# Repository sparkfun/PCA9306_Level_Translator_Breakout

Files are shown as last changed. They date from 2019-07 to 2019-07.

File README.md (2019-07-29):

PCA9306 Level Translator Breakout
=================================

PCA9306 Level Translator Breakout (https://www.sparkfun.com/products/15439)

[*PCA9306 Level Translator Breakout(BOB-15439)*](https://www.sparkfun.com/products/15439)

This is a breakout board for the PCA9306 dual bidirectional voltage-level translator. 

Repository Contents
-------------------
* **/Hardware** - Eagle design files for the board (.brd, .sch)

Documentation
--------------
* **[Hookup Guide](https://learn.sparkfun.com/tutorials/pca9306-logic-level-translator-hookup-guide-v2)** - Basic hookup guide for the PCA9306 logic level translator.
* **[Logic Levels](https://learn.sparkfun.com/tutorials/logic-levels)**
* **[SparkFun Fritzing repo](https://github.com/sparkfun/Fritzing_Parts)** - Fritzing diagrams for SparkFun products.

License Information
-------------------
The hardware is released under [Creative Commons Share-alike 3.0](http://creativecommons.org/licenses/by-sa/3.0/).

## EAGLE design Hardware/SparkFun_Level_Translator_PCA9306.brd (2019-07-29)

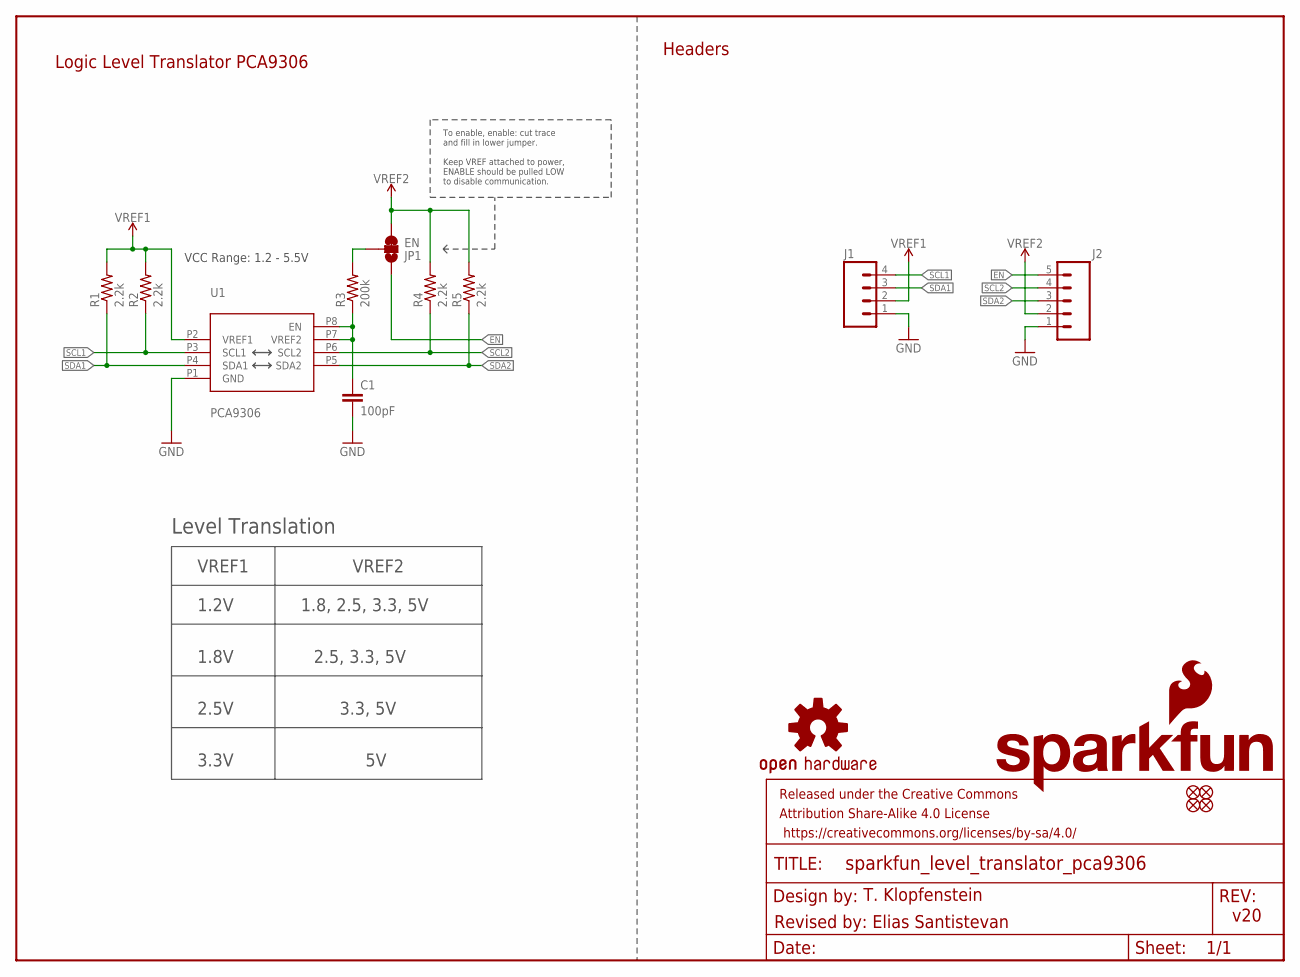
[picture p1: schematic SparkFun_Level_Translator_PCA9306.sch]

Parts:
C1: 100pF; 0603
FD1, FD2, FD3, FD4: FIDUCIALUFIDUCIAL; FIDUCIAL-MICRO
FRAME1: FRAME-LETTER; CREATIVE_COMMONS
J1: CONN_041X04_NO_SILK; 1X04_NO_SILK
J2: CONN_05NO_SILK; 1X05_NO_SILK
JP1: EN; SMT-JUMPER_3_1-NC_TRACE_SILK
LOGO1: OSHW-LOGOMINI; OSHW-LOGO-MINI
LOGO2: SFE_LOGO_NAME.1_INCH; SFE_LOGO_NAME_.1
LOGO3: SFE_LOGO_FLAME.1_INCH; SFE_LOGO_FLAME_.1
R1, R2, R4, R5: 2.2k; 0603
R3: 200k; 0603
U1: PCA9306; VSSOP_8PIN

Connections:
EN: J2.5, JP1.1
GND: C1.2, J1.1, J2.1, U1.P1 (GND)
JUMPER_IN: JP1.2, R3.2
SCL1: J1.4, R2.1, U1.P3 (SCL1)
SCL2: J2.4, R4.1, U1.P6 (SCL2)
SDA1: J1.3, R1.1, U1.P4 (SDA1)
SDA2: J2.3, R5.1, U1.P5 (SDA2)
VREF1: J1.2, R1.2, R2.2, U1.P2 (VREF1)
VREF2: J2.2, JP1.3, R4.2, R5.2
VREF2_IN: C1.1, R3.1, U1.P7 (VREF2), U1.P8 (EN)

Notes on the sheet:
T. Klopfenstein
v20
Logic Level Translator PCA9306
Headers
Revised by: Elias Santistevan
Level Translation
VREF1
VREF2
1.2V
1.8, 2.5, 3.3, 5V
1.8V
2.5, 3.3, 5V
2.5V
3.3, 5V
3.3V
VCC Range: 1.2 - 5.5V
To enable, enable: cut trace and fill in lower jumper.
Keep VREF attached to power, ENABLE should be pulled LOW to disable communication.

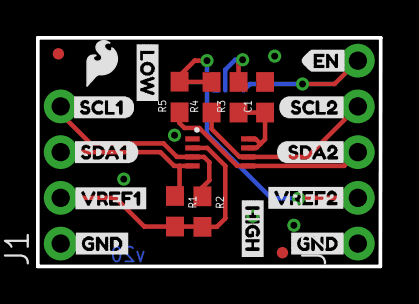
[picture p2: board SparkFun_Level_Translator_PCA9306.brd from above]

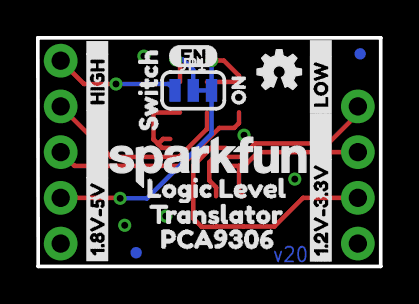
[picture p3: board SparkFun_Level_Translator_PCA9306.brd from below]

Board: 2 copper layers, 19.1 x 12.7 mm, 39 parts (15 on the bottom side), 10 nets.

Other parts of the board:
U$1: SWITCH1
U$2: VREF13
U$3: SCL11
U$4: SDA10
U$5, U$11: GND2
U$6: VREF20
U$7: SCL20
U$8: SDA21
U$9: EN0
U$10: EN1
U$12: LOGIC_LEVEL0
U$13: TRANSLATOR1
U$14: PCA93062
U$15: ON2
U$17, U$19: HIGH0
U$18, U$20: LOW1
U$21: 1#2V#3#3V0
U$22: 1#8V#5V1

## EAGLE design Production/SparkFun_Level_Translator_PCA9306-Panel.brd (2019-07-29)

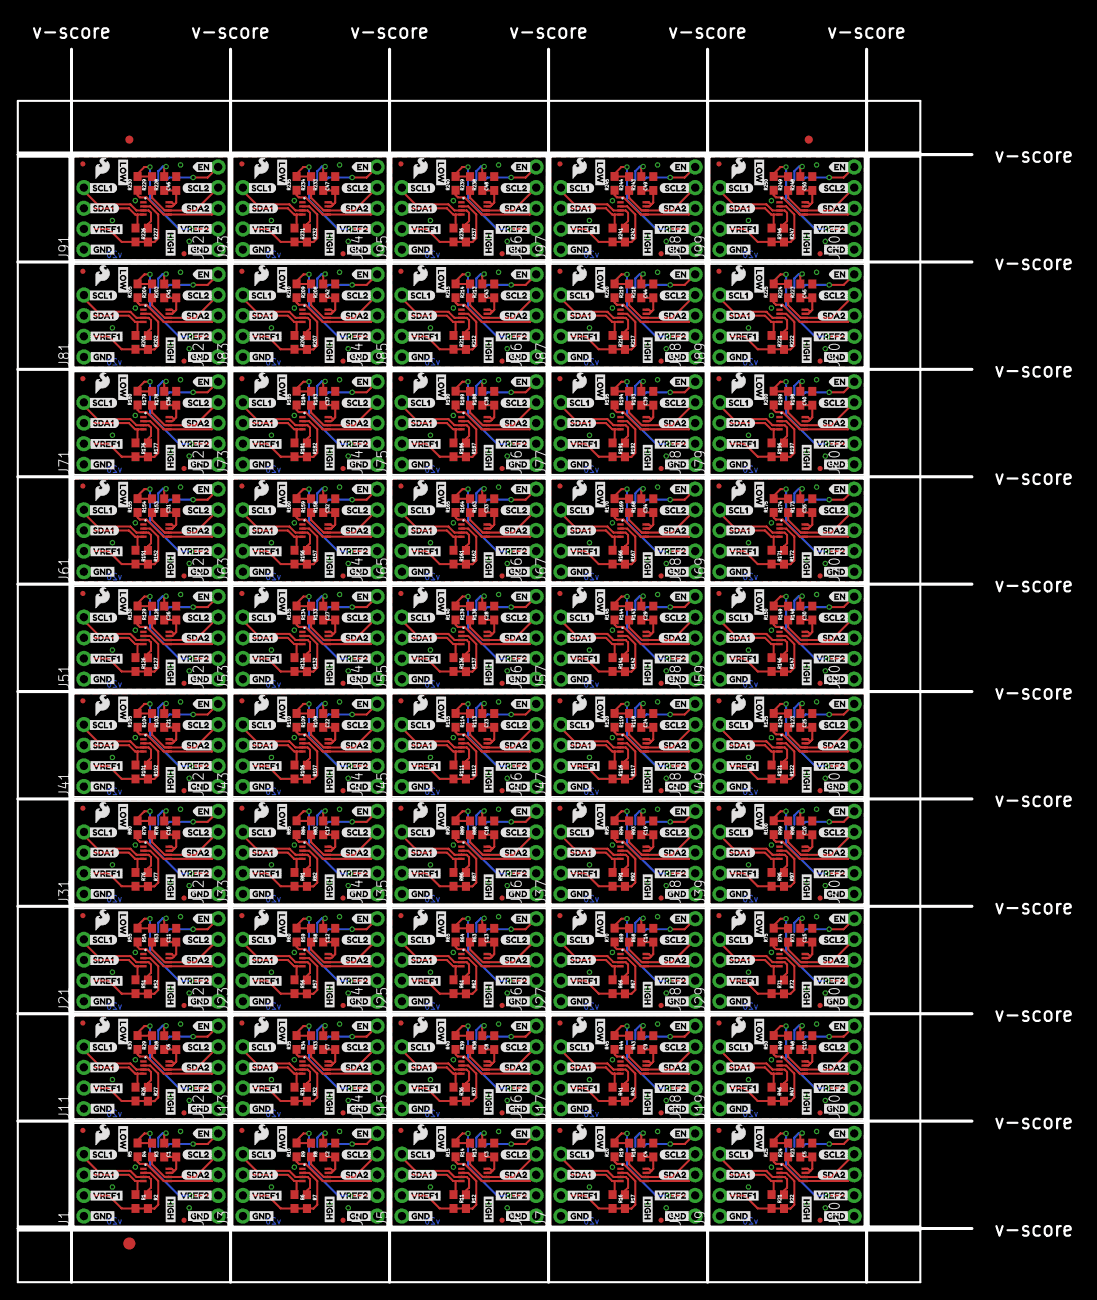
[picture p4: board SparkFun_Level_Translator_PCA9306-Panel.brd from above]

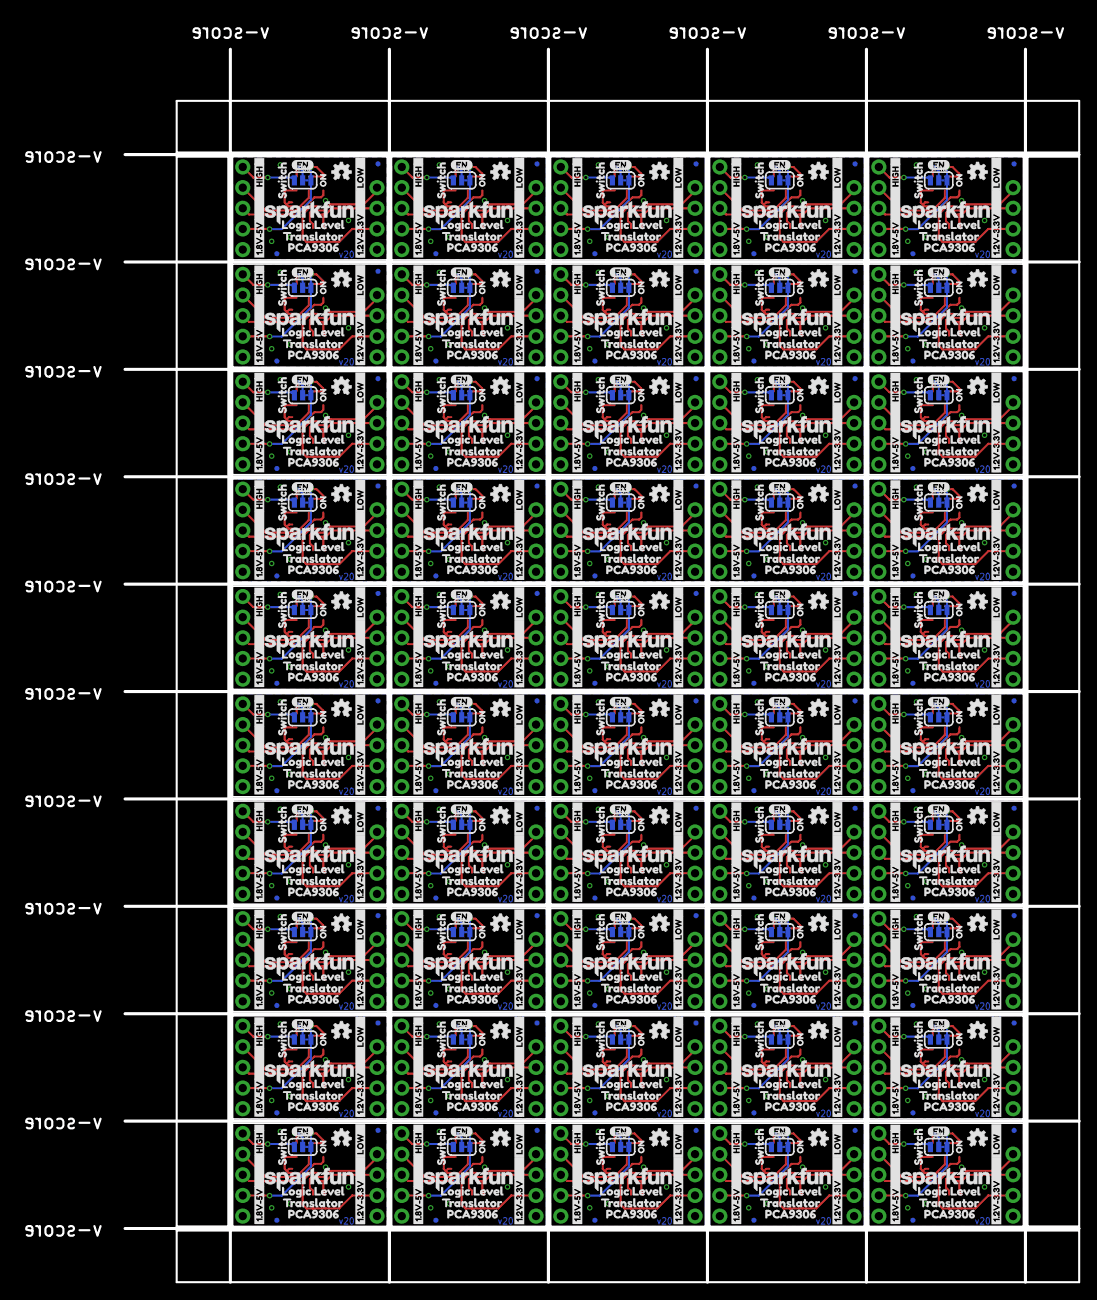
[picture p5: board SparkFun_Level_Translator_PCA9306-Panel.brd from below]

Board: 2 copper layers, 117.3 x 151.6 mm, 1903 parts (750 on the bottom side), 500 nets.

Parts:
C1, C2, C3, C4, C5, C6, C7, C8, C9, C10, C11, C12, C13, C14, C15, C16, C17, C18, C19, C20, C21, C22, C23, C24, C25, C26, C27, C28, C29, C30, C31, C32, C33, C34, C35, C36, C37, C38, C39, C40, C41, C42, C43, C44, C45, C46, C47, C48, C49, C50: 100pF; 0603
E$1, E$2: FIDUCIAL-1X2
E$3: FIDUCIAL-1.5X3
FD1, FD2, FD3, FD4, FD5, FD6, FD7, FD8, FD9, FD10, FD11, FD12, FD13, FD14, FD15, FD16, FD17, FD18, FD19, FD20, FD21, FD22, FD23, FD24, FD25, FD26, FD27, FD28, FD29, FD30, FD31, FD32, FD33, FD34, FD35, FD36, FD37, FD38, FD39, FD40, FD41, FD42, FD43, FD44, FD45, FD46, FD47, FD48, FD49, FD50, FD51, FD52, FD53, FD54, FD55, FD56, FD57, FD58, FD59, FD60, FD61, FD62, FD63, FD64, FD65, FD66, FD67, FD68, FD69, FD70, FD71, FD72, FD73, FD74, FD75, FD76, FD77, FD78, FD79, FD80, FD81, FD82, FD83, FD84, FD85, FD86, FD87, FD88, FD89, FD90, FD91, FD92, FD93, FD94, FD95, FD96, FD97, FD98, FD99, FD100, FD101, FD102, FD103, FD104, FD105, FD106, FD107, FD108, FD109, FD110, FD111, FD112, FD113, FD114, FD115, FD116, FD117, FD118, FD119, FD120, FD121, FD122, FD123, FD124, FD125, FD126, FD127, FD128, FD129, FD130, FD131, FD132, FD133, FD134, FD135, FD136, FD137, FD138, FD139, FD140, FD141, FD142, FD143, FD144, FD145, FD146, FD147, FD148, FD149, FD150, FD151, FD152, FD153, FD154, FD155, FD156, FD157, FD158, FD159, FD160, FD161, FD162, FD163, FD164, FD165, FD166, FD167, FD168, FD169, FD170, FD171, FD172, FD173, FD174, FD175, FD176, FD177, FD178, FD179, FD180, FD181, FD182, FD183, FD184, FD185, FD186, FD187, FD188, FD189, FD190, FD191, FD192, FD193, FD194, FD195, FD196, FD197, FD198, FD199, FD200: FIDUCIALUFIDUCIAL; FIDUCIAL-MICRO
J1, J3, J5, J7, J9, J11, J13, J15, J17, J19, J21, J23, J25, J27, J29, J31, J33, J35, J37, J39, J41, J43, J45, J47, J49, J51, J53, J55, J57, J59, J61, J63, J65, J67, J69, J71, J73, J75, J77, J79, J81, J83, J85, J87, J89, J91, J93, J95, J97, J99: 1X04_NO_SILK
J2, J4, J6, J8, J10, J12, J14, J16, J18, J20, J22, J24, J26, J28, J30, J32, J34, J36, J38, J40, J42, J44, J46, J48, J50, J52, J54, J56, J58, J60, J62, J64, J66, J68, J70, J72, J74, J76, J78, J80, J82, J84, J86, J88, J90, J92, J94, J96, J98, J100: 1X05_NO_SILK
JP1, JP2, JP3, JP4, JP5, JP6, JP7, JP8, JP9, JP10, JP11, JP12, JP13, JP14, JP15, JP16, JP17, JP18, JP19, JP20, JP21, JP22, JP23, JP24, JP25, JP26, JP27, JP28, JP29, JP30, JP31, JP32, JP33, JP34, JP35, JP36, JP37, JP38, JP39, JP40, JP41, JP42, JP43, JP44, JP45, JP46, JP47, JP48, JP49, JP50: EN; SMT-JUMPER_3_1-NC_TRACE_SILK
LOGO1, LOGO6, LOGO9, LOGO12, LOGO15, LOGO18, LOGO21, LOGO24, LOGO27, LOGO30, LOGO33, LOGO36, LOGO39, LOGO42, LOGO45, LOGO48, LOGO51, LOGO54, LOGO57, LOGO60, LOGO63, LOGO66, LOGO69, LOGO72, LOGO75, LOGO78, LOGO81, LOGO84, LOGO87, LOGO90, LOGO93, LOGO96, LOGO99, LOGO102, LOGO105, LOGO108, LOGO111, LOGO114, LOGO117, LOGO120, LOGO123, LOGO126, LOGO129, LOGO132, LOGO135, LOGO138, LOGO141, LOGO144, LOGO147, LOGO150: OSHW-LOGOMINI; OSHW-LOGO-MINI
LOGO2, LOGO5, LOGO8, LOGO11, LOGO14, LOGO17, LOGO20, LOGO23, LOGO26, LOGO29, LOGO32, LOGO35, LOGO38, LOGO41, LOGO44, LOGO47, LOGO50, LOGO53, LOGO56, LOGO59, LOGO62, LOGO65, LOGO68, LOGO71, LOGO74, LOGO77, LOGO80, LOGO83, LOGO86, LOGO89, LOGO92, LOGO95, LOGO98, LOGO101, LOGO104, LOGO107, LOGO110, LOGO113, LOGO116, LOGO119, LOGO122, LOGO125, LOGO128, LOGO131, LOGO134, LOGO137, LOGO140, LOGO143, LOGO146, LOGO149: SFE_LOGO_NAME.1_INCH; SFE_LOGO_NAME_.1
LOGO3, LOGO4, LOGO7, LOGO10, LOGO13, LOGO16, LOGO19, LOGO22, LOGO25, LOGO28, LOGO31, LOGO34, LOGO37, LOGO40, LOGO43, LOGO46, LOGO49, LOGO52, LOGO55, LOGO58, LOGO61, LOGO64, LOGO67, LOGO70, LOGO73, LOGO76, LOGO79, LOGO82, LOGO85, LOGO88, LOGO91, LOGO94, LOGO97, LOGO100, LOGO103, LOGO106, LOGO109, LOGO112, LOGO115, LOGO118, LOGO121, LOGO124, LOGO127, LOGO130, LOGO133, LOGO136, LOGO139, LOGO142, LOGO145, LOGO148: SFE_LOGO_FLAME.1_INCH; SFE_LOGO_FLAME_.1
R1, R2, R4, R5, R6, R7, R9, R10, R11, R12, R14, R15, R16, R17, R19, R20, R21, R22, R24, R25, R26, R27, R29, R30, R31, R32, R34, R35, R36, R37, R39, R40, R41, R42, R44, R45, R46, R47, R49, R50, R51, R52, R54, R55, R56, R57, R59, R60, R61, R62, R64, R65, R66, R67, R69, R70, R71, R72, R74, R75, R76, R77, R79, R80, R81, R82, R84, R85, R86, R87, R89, R90, R91, R92, R94, R95, R96, R97, R99, R100, R101, R102, R104, R105, R106, R107, R109, R110, R111, R112, R114, R115, R116, R117, R119, R120, R121, R122, R124, R125, R126, R127, R129, R130, R131, R132, R134, R135, R136, R137, R139, R140, R141, R142, R144, R145, R146, R147, R149, R150, R151, R152, R154, R155, R156, R157, R159, R160, R161, R162, R164, R165, R166, R167, R169, R170, R171, R172, R174, R175, R176, R177, R179, R180, R181, R182, R184, R185, R186, R187, R189, R190, R191, R192, R194, R195, R196, R197, R199, R200, R201, R202, R204, R205, R206, R207, R209, R210, R211, R212, R214, R215, R216, R217, R219, R220, R221, R222, R224, R225, R226, R227, R229, R230, R231, R232, R234, R235, R236, R237, R239, R240, R241, R242, R244, R245, R246, R247, R249, R250: 2.2k; 0603
R3, R8, R13, R18, R23, R28, R33, R38, R43, R48, R53, R58, R63, R68, R73, R78, R83, R88, R93, R98, R103, R108, R113, R118, R123, R128, R133, R138, R143, R148, R153, R158, R163, R168, R173, R178, R183, R188, R193, R198, R203, R208, R213, R218, R223, R228, R233, R238, R243, R248: 200k; 0603
U1, U2, U3, U4, U5, U6, U7, U8, U9, U10, U11, U12, U13, U14, U15, U16, U17, U18, U19, U20, U21, U22, U23, U24, U25, U26, U27, U28, U29, U30, U31, U32, U33, U34, U35, U36, U37, U38, U39, U40, U41, U42, U43, U44, U45, U46, U47, U48, U49, U50: PCA9306; VSSOP_8PIN
U$1, U$42, U$63, U$84, U$105, U$126, U$147, U$168, U$189, U$210, U$231, U$252, U$273, U$294, U$315, U$336, U$357, U$378, U$399, U$420, U$441, U$462, U$483, U$504, U$525, U$546, U$567, U$588, U$609, U$630, U$651, U$672, U$693, U$714, U$735, U$756, U$777, U$798, U$819, U$840, U$861, U$882, U$903, U$924, U$945, U$966, U$987, U$1008, U$1029, U$1050: SWITCH1
U$2, U$16, U$43, U$64, U$85, U$106, U$127, U$148, U$169, U$190, U$211, U$232, U$253, U$274, U$295, U$316, U$337, U$358, U$379, U$400, U$421, U$442, U$463, U$484, U$505, U$526, U$547, U$568, U$589, U$610, U$631, U$652, U$673, U$694, U$715, U$736, U$757, U$778, U$799, U$820, U$841, U$862, U$883, U$904, U$925, U$946, U$967, U$988, U$1009, U$1030: VREF13
U$3, U$23, U$44, U$65, U$86, U$107, U$128, U$149, U$170, U$191, U$212, U$233, U$254, U$275, U$296, U$317, U$338, U$359, U$380, U$401, U$422, U$443, U$464, U$485, U$506, U$527, U$548, U$569, U$590, U$611, U$632, U$653, U$674, U$695, U$716, U$737, U$758, U$779, U$800, U$821, U$842, U$863, U$884, U$905, U$926, U$947, U$968, U$989, U$1010, U$1031: SCL11
U$4, U$24, U$45, U$66, U$87, U$108, U$129, U$150, U$171, U$192, U$213, U$234, U$255, U$276, U$297, U$318, U$339, U$360, U$381, U$402, U$423, U$444, U$465, U$486, U$507, U$528, U$549, U$570, U$591, U$612, U$633, U$654, U$675, U$696, U$717, U$738, U$759, U$780, U$801, U$822, U$843, U$864, U$885, U$906, U$927, U$948, U$969, U$990, U$1011, U$1032: SDA10
U$5, U$11, U$25, U$33, U$46, U$54, U$67, U$75, U$88, U$96, U$109, U$117, U$130, U$138, U$151, U$159, U$172, U$180, U$193, U$201, U$214, U$222, U$235, U$243, U$256, U$264, U$277, U$285, U$298, U$306, U$319, U$327, U$340, U$348, U$361, U$369, U$382, U$390, U$403, U$411, U$424, U$432, U$445, U$453, U$466, U$474, U$487, U$495, U$508, U$516, U$529, U$537, U$550, U$558, U$571, U$579, U$592, U$600, U$613, U$621, U$634, U$642, U$655, U$663, U$676, U$684, U$697, U$705, U$718, U$726, U$739, U$747, U$760, U$768, U$781, U$789, U$802, U$810, U$823, U$831, U$844, U$852, U$865, U$873, U$886, U$894, U$907, U$915, U$928, U$936, U$949, U$957, U$970, U$978, U$991, U$999, U$1012, U$1020, U$1033, U$1041: GND2
U$6, U$26, U$47, U$68, U$89, U$110, U$131, U$152, U$173, U$194, U$215, U$236, U$257, U$278, U$299, U$320, U$341, U$362, U$383, U$404, U$425, U$446, U$467, U$488, U$509, U$530, U$551, U$572, U$593, U$614, U$635, U$656, U$677, U$698, U$719, U$740, U$761, U$782, U$803, U$824, U$845, U$866, U$887, U$908, U$929, U$950, U$971, U$992, U$1013, U$1034: VREF20
U$7, U$34, U$55, U$76, U$97, U$118, U$139, U$160, U$181, U$202, U$223, U$244, U$265, U$286, U$307, U$328, U$349, U$370, U$391, U$412, U$433, U$454, U$475, U$496, U$517, U$538, U$559, U$580, U$601, U$622, U$643, U$664, U$685, U$706, U$727, U$748, U$769, U$790, U$811, U$832, U$853, U$874, U$895, U$916, U$937, U$958, U$979, U$1000, U$1021, U$1042: SCL20
U$8, U$27, U$48, U$69, U$90, U$111, U$132, U$153, U$174, U$195, U$216, U$237, U$258, U$279, U$300, U$321, U$342, U$363, U$384, U$405, U$426, U$447, U$468, U$489, U$510, U$531, U$552, U$573, U$594, U$615, U$636, U$657, U$678, U$699, U$720, U$741, U$762, U$783, U$804, U$825, U$846, U$867, U$888, U$909, U$930, U$951, U$972, U$993, U$1014, U$1035: SDA21
U$9, U$28, U$49, U$70, U$91, U$112, U$133, U$154, U$175, U$196, U$217, U$238, U$259, U$280, U$301, U$322, U$343, U$364, U$385, U$406, U$427, U$448, U$469, U$490, U$511, U$532, U$553, U$574, U$595, U$616, U$637, U$658, U$679, U$700, U$721, U$742, U$763, U$784, U$805, U$826, U$847, U$868, U$889, U$910, U$931, U$952, U$973, U$994, U$1015, U$1036: EN0
U$10, U$29, U$50, U$71, U$92, U$113, U$134, U$155, U$176, U$197, U$218, U$239, U$260, U$281, U$302, U$323, U$344, U$365, U$386, U$407, U$428, U$449, U$470, U$491, U$512, U$533, U$554, U$575, U$596, U$617, U$638, U$659, U$680, U$701, U$722, U$743, U$764, U$785, U$806, U$827, U$848, U$869, U$890, U$911, U$932, U$953, U$974, U$995, U$1016, U$1037: EN1
U$12, U$30, U$51, U$72, U$93, U$114, U$135, U$156, U$177, U$198, U$219, U$240, U$261, U$282, U$303, U$324, U$345, U$366, U$387, U$408, U$429, U$450, U$471, U$492, U$513, U$534, U$555, U$576, U$597, U$618, U$639, U$660, U$681, U$702, U$723, U$744, U$765, U$786, U$807, U$828, U$849, U$870, U$891, U$912, U$933, U$954, U$975, U$996, U$1017, U$1038: LOGIC_LEVEL0
U$13, U$31, U$52, U$73, U$94, U$115, U$136, U$157, U$178, U$199, U$220, U$241, U$262, U$283, U$304, U$325, U$346, U$367, U$388, U$409, U$430, U$451, U$472, U$493, U$514, U$535, U$556, U$577, U$598, U$619, U$640, U$661, U$682, U$703, U$724, U$745, U$766, U$787, U$808, U$829, U$850, U$871, U$892, U$913, U$934, U$955, U$976, U$997, U$1018, U$1039: TRANSLATOR1
U$14, U$32, U$53, U$74, U$95, U$116, U$137, U$158, U$179, U$200, U$221, U$242, U$263, U$284, U$305, U$326, U$347, U$368, U$389, U$410, U$431, U$452, U$473, U$494, U$515, U$536, U$557, U$578, U$599, U$620, U$641, U$662, U$683, U$704, U$725, U$746, U$767, U$788, U$809, U$830, U$851, U$872, U$893, U$914, U$935, U$956, U$977, U$998, U$1019, U$1040: PCA93062
U$15, U$39, U$60, U$81, U$102, U$123, U$144, U$165, U$186, U$207, U$228, U$249, U$270, U$291, U$312, U$333, U$354, U$375, U$396, U$417, U$438, U$459, U$480, U$501, U$522, U$543, U$564, U$585, U$606, U$627, U$648, U$669, U$690, U$711, U$732, U$753, U$774, U$795, U$816, U$837, U$858, U$879, U$900, U$921, U$942, U$963, U$984, U$1005, U$1026, U$1047: ON2
U$17, U$19, U$35, U$37, U$56, U$58, U$77, U$79, U$98, U$100, U$119, U$121, U$140, U$142, U$161, U$163, U$182, U$184, U$203, U$205, U$224, U$226, U$245, U$247, U$266, U$268, U$287, U$289, U$308, U$310, U$329, U$331, U$350, U$352, U$371, U$373, U$392, U$394, U$413, U$415, U$434, U$436, U$455, U$457, U$476, U$478, U$497, U$499, U$518, U$520, U$539, U$541, U$560, U$562, U$581, U$583, U$602, U$604, U$623, U$625, U$644, U$646, U$665, U$667, U$686, U$688, U$707, U$709, U$728, U$730, U$749, U$751, U$770, U$772, U$791, U$793, U$812, U$814, U$833, U$835, U$854, U$856, U$875, U$877, U$896, U$898, U$917, U$919, U$938, U$940, U$959, U$961, U$980, U$982, U$1001, U$1003, U$1022, U$1024, U$1043, U$1045: HIGH0
U$18, U$20, U$36, U$38, U$57, U$59, U$78, U$80, U$99, U$101, U$120, U$122, U$141, U$143, U$162, U$164, U$183, U$185, U$204, U$206, U$225, U$227, U$246, U$248, U$267, U$269, U$288, U$290, U$309, U$311, U$330, U$332, U$351, U$353, U$372, U$374, U$393, U$395, U$414, U$416, U$435, U$437, U$456, U$458, U$477, U$479, U$498, U$500, U$519, U$521, U$540, U$542, U$561, U$563, U$582, U$584, U$603, U$605, U$624, U$626, U$645, U$647, U$666, U$668, U$687, U$689, U$708, U$710, U$729, U$731, U$750, U$752, U$771, U$773, U$792, U$794, U$813, U$815, U$834, U$836, U$855, U$857, U$876, U$878, U$897, U$899, U$918, U$920, U$939, U$941, U$960, U$962, U$981, U$983, U$1002, U$1004, U$1023, U$1025, U$1044, U$1046: LOW1
U$21, U$40, U$61, U$82, U$103, U$124, U$145, U$166, U$187, U$208, U$229, U$250, U$271, U$292, U$313, U$334, U$355, U$376, U$397, U$418, U$439, U$460, U$481, U$502, U$523, U$544, U$565, U$586, U$607, U$628, U$649, U$670, U$691, U$712, U$733, U$754, U$775, U$796, U$817, U$838, U$859, U$880, U$901, U$922, U$943, U$964, U$985, U$1006, U$1027, U$1048: 1#2V#3#3V0
U$22, U$41, U$62, U$83, U$104, U$125, U$146, U$167, U$188, U$209, U$230, U$251, U$272, U$293, U$314, U$335, U$356, U$377, U$398, U$419, U$440, U$461, U$482, U$503, U$524, U$545, U$566, U$587, U$608, U$629, U$650, U$671, U$692, U$713, U$734, U$755, U$776, U$797, U$818, U$839, U$860, U$881, U$902, U$923, U$944, U$965, U$986, U$1007, U$1028, U$1049: 1#8V#5V1

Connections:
EN: J2.5, JP1.1
EN1: J4.5, JP2.1
EN2: J6.5, JP3.1
EN3: J8.5, JP4.1
EN4: J10.5, JP5.1
EN5: J12.5, JP6.1
EN6: J14.5, JP7.1
EN7: J16.5, JP8.1
EN8: J18.5, JP9.1
EN9: J20.5, JP10.1
EN10: J22.5, JP11.1
EN11: J24.5, JP12.1
EN12: J26.5, JP13.1
EN13: J28.5, JP14.1
EN14: J30.5, JP15.1
EN15: J32.5, JP16.1
EN16: J34.5, JP17.1
EN17: J36.5, JP18.1
EN18: J38.5, JP19.1
EN19: J40.5, JP20.1
EN20: J42.5, JP21.1
EN21: J44.5, JP22.1
EN22: J46.5, JP23.1
EN23: J48.5, JP24.1
EN24: J50.5, JP25.1
EN25: J52.5, JP26.1
EN26: J54.5, JP27.1
EN27: J56.5, JP28.1
EN28: J58.5, JP29.1
EN29: J60.5, JP30.1
EN30: J62.5, JP31.1
EN31: J64.5, JP32.1
EN32: J66.5, JP33.1
EN33: J68.5, JP34.1
EN34: J70.5, JP35.1
EN35: J72.5, JP36.1
EN36: J74.5, JP37.1
EN37: J76.5, JP38.1
EN38: J78.5, JP39.1
EN39: J80.5, JP40.1
EN40: J82.5, JP41.1
EN41: J84.5, JP42.1
EN42: J86.5, JP43.1
EN43: J88.5, JP44.1
EN44: J90.5, JP45.1
EN45: J92.5, JP46.1
EN46: J94.5, JP47.1
EN47: J96.5, JP48.1
EN48: J98.5, JP49.1
EN49: J100.5, JP50.1
GND: C1.2, J1.1, J2.1, U1.P1
GND1: C2.2, J3.1, J4.1, U2.P1
GND2: C3.2, J5.1, J6.1, U3.P1
GND3: C4.2, J7.1, J8.1, U4.P1
GND4: C5.2, J9.1, J10.1, U5.P1
GND5: C6.2, J11.1, J12.1, U6.P1
GND6: C7.2, J13.1, J14.1, U7.P1
GND7: C8.2, J15.1, J16.1, U8.P1
GND8: C9.2, J17.1, J18.1, U9.P1
GND9: C10.2, J19.1, J20.1, U10.P1
GND10: C11.2, J21.1, J22.1, U11.P1
GND11: C12.2, J23.1, J24.1, U12.P1
GND12: C13.2, J25.1, J26.1, U13.P1
GND13: C14.2, J27.1, J28.1, U14.P1
GND14: C15.2, J29.1, J30.1, U15.P1
GND15: C16.2, J31.1, J32.1, U16.P1
GND16: C17.2, J33.1, J34.1, U17.P1
GND17: C18.2, J35.1, J36.1, U18.P1
GND18: C19.2, J37.1, J38.1, U19.P1
GND19: C20.2, J39.1, J40.1, U20.P1
GND20: C21.2, J41.1, J42.1, U21.P1
GND21: C22.2, J43.1, J44.1, U22.P1
GND22: C23.2, J45.1, J46.1, U23.P1
GND23: C24.2, J47.1, J48.1, U24.P1
GND24: C25.2, J49.1, J50.1, U25.P1
GND25: C26.2, J51.1, J52.1, U26.P1
GND26: C27.2, J53.1, J54.1, U27.P1
GND27: C28.2, J55.1, J56.1, U28.P1
GND28: C29.2, J57.1, J58.1, U29.P1
GND29: C30.2, J59.1, J60.1, U30.P1
GND30: C31.2, J61.1, J62.1, U31.P1
GND31: C32.2, J63.1, J64.1, U32.P1
GND32: C33.2, J65.1, J66.1, U33.P1
GND33: C34.2, J67.1, J68.1, U34.P1
GND34: C35.2, J69.1, J70.1, U35.P1
GND35: C36.2, J71.1, J72.1, U36.P1
GND36: C37.2, J73.1, J74.1, U37.P1
GND37: C38.2, J75.1, J76.1, U38.P1
GND38: C39.2, J77.1, J78.1, U39.P1
GND39: C40.2, J79.1, J80.1, U40.P1
GND40: C41.2, J81.1, J82.1, U41.P1
GND41: C42.2, J83.1, J84.1, U42.P1
GND42: C43.2, J85.1, J86.1, U43.P1
GND43: C44.2, J87.1, J88.1, U44.P1
GND44: C45.2, J89.1, J90.1, U45.P1
GND45: C46.2, J91.1, J92.1, U46.P1
GND46: C47.2, J93.1, J94.1, U47.P1
GND47: C48.2, J95.1, J96.1, U48.P1
GND48: C49.2, J97.1, J98.1, U49.P1
GND49: C50.2, J99.1, J100.1, U50.P1
JUMPER_IN: JP1.2, R3.2
JUMPER_IN1: JP2.2, R8.2
JUMPER_IN2: JP3.2, R13.2
JUMPER_IN3: JP4.2, R18.2
JUMPER_IN4: JP5.2, R23.2
JUMPER_IN5: JP6.2, R28.2
JUMPER_IN6: JP7.2, R33.2
JUMPER_IN7: JP8.2, R38.2
JUMPER_IN8: JP9.2, R43.2
JUMPER_IN9: JP10.2, R48.2
JUMPER_IN10: JP11.2, R53.2
JUMPER_IN11: JP12.2, R58.2
JUMPER_IN12: JP13.2, R63.2
JUMPER_IN13: JP14.2, R68.2
JUMPER_IN14: JP15.2, R73.2
JUMPER_IN15: JP16.2, R78.2
JUMPER_IN16: JP17.2, R83.2
JUMPER_IN17: JP18.2, R88.2
JUMPER_IN18: JP19.2, R93.2
JUMPER_IN19: JP20.2, R98.2
JUMPER_IN20: JP21.2, R103.2
JUMPER_IN21: JP22.2, R108.2
JUMPER_IN22: JP23.2, R113.2
JUMPER_IN23: JP24.2, R118.2
JUMPER_IN24: JP25.2, R123.2
JUMPER_IN25: JP26.2, R128.2
JUMPER_IN26: JP27.2, R133.2
JUMPER_IN27: JP28.2, R138.2
JUMPER_IN28: JP29.2, R143.2
JUMPER_IN29: JP30.2, R148.2
JUMPER_IN30: JP31.2, R153.2
JUMPER_IN31: JP32.2, R158.2
JUMPER_IN32: JP33.2, R163.2
JUMPER_IN33: JP34.2, R168.2
JUMPER_IN34: JP35.2, R173.2
JUMPER_IN35: JP36.2, R178.2
JUMPER_IN36: JP37.2, R183.2
JUMPER_IN37: JP38.2, R188.2
JUMPER_IN38: JP39.2, R193.2
JUMPER_IN39: JP40.2, R198.2
JUMPER_IN40: JP41.2, R203.2
JUMPER_IN41: JP42.2, R208.2
JUMPER_IN42: JP43.2, R213.2
JUMPER_IN43: JP44.2, R218.2
JUMPER_IN44: JP45.2, R223.2
JUMPER_IN45: JP46.2, R228.2
JUMPER_IN46: JP47.2, R233.2
JUMPER_IN47: JP48.2, R238.2
JUMPER_IN48: JP49.2, R243.2
JUMPER_IN49: JP50.2, R248.2
SCL1: J1.4, R2.1, U1.P3
SCL2: J2.4, R4.1, U1.P6
SCL3: J3.4, R7.1, U2.P3
SCL4: J4.4, R9.1, U2.P6
SCL5: J5.4, R12.1, U3.P3
SCL6: J6.4, R14.1, U3.P6
SCL7: J7.4, R17.1, U4.P3
SCL8: J8.4, R19.1, U4.P6
SCL9: J9.4, R22.1, U5.P3
SCL10: J10.4, R24.1, U5.P6
SCL11: J11.4, R27.1, U6.P3
SCL12: J12.4, R29.1, U6.P6
SCL13: J13.4, R32.1, U7.P3
SCL14: J14.4, R34.1, U7.P6
SCL15: J15.4, R37.1, U8.P3
SCL16: J16.4, R39.1, U8.P6
SCL17: J17.4, R42.1, U9.P3
SCL18: J18.4, R44.1, U9.P6
SCL19: J19.4, R47.1, U10.P3
SCL20: J20.4, R49.1, U10.P6
SCL21: J21.4, R52.1, U11.P3
SCL22: J22.4, R54.1, U11.P6
SCL23: J23.4, R57.1, U12.P3
SCL24: J24.4, R59.1, U12.P6
SCL25: J25.4, R62.1, U13.P3
SCL26: J26.4, R64.1, U13.P6
SCL27: J27.4, R67.1, U14.P3
SCL28: J28.4, R69.1, U14.P6
SCL29: J29.4, R72.1, U15.P3
SCL30: J30.4, R74.1, U15.P6
SCL31: J31.4, R77.1, U16.P3
SCL32: J32.4, R79.1, U16.P6
SCL33: J33.4, R82.1, U17.P3
SCL34: J34.4, R84.1, U17.P6
SCL35: J35.4, R87.1, U18.P3
SCL36: J36.4, R89.1, U18.P6
SCL37: J37.4, R92.1, U19.P3
SCL38: J38.4, R94.1, U19.P6
SCL39: J39.4, R97.1, U20.P3
SCL40: J40.4, R99.1, U20.P6
SCL41: J41.4, R102.1, U21.P3
SCL42: J42.4, R104.1, U21.P6
SCL43: J43.4, R107.1, U22.P3
SCL44: J44.4, R109.1, U22.P6
SCL45: J45.4, R112.1, U23.P3
SCL46: J46.4, R114.1, U23.P6
SCL47: J47.4, R117.1, U24.P3
SCL48: J48.4, R119.1, U24.P6
SCL49: J49.4, R122.1, U25.P3
SCL50: J50.4, R124.1, U25.P6
SCL51: J51.4, R127.1, U26.P3
SCL52: J52.4, R129.1, U26.P6
SCL53: J53.4, R132.1, U27.P3
SCL54: J54.4, R134.1, U27.P6
SCL55: J55.4, R137.1, U28.P3
SCL56: J56.4, R139.1, U28.P6
SCL57: J57.4, R142.1, U29.P3
SCL58: J58.4, R144.1, U29.P6
SCL59: J59.4, R147.1, U30.P3
SCL60: J60.4, R149.1, U30.P6
SCL61: J61.4, R152.1, U31.P3
SCL62: J62.4, R154.1, U31.P6
SCL63: J63.4, R157.1, U32.P3
SCL64: J64.4, R159.1, U32.P6
SCL65: J65.4, R162.1, U33.P3
SCL66: J66.4, R164.1, U33.P6
SCL67: J67.4, R167.1, U34.P3
SCL68: J68.4, R169.1, U34.P6
SCL69: J69.4, R172.1, U35.P3
SCL70: J70.4, R174.1, U35.P6
SCL71: J71.4, R177.1, U36.P3
SCL72: J72.4, R179.1, U36.P6
SCL73: J73.4, R182.1, U37.P3
SCL74: J74.4, R184.1, U37.P6
SCL75: J75.4, R187.1, U38.P3
SCL76: J76.4, R189.1, U38.P6
SCL77: J77.4, R192.1, U39.P3
SCL78: J78.4, R194.1, U39.P6
SCL79: J79.4, R197.1, U40.P3
SCL80: J80.4, R199.1, U40.P6
SCL81: J81.4, R202.1, U41.P3
SCL82: J82.4, R204.1, U41.P6
SCL83: J83.4, R207.1, U42.P3
SCL84: J84.4, R209.1, U42.P6
SCL85: J85.4, R212.1, U43.P3
SCL86: J86.4, R214.1, U43.P6
SCL87: J87.4, R217.1, U44.P3
SCL88: J88.4, R219.1, U44.P6
SCL89: J89.4, R222.1, U45.P3
SCL90: J90.4, R224.1, U45.P6
SCL91: J91.4, R227.1, U46.P3
SCL92: J92.4, R229.1, U46.P6
SCL93: J93.4, R232.1, U47.P3
SCL94: J94.4, R234.1, U47.P6
SCL95: J95.4, R237.1, U48.P3
SCL96: J96.4, R239.1, U48.P6
SCL97: J97.4, R242.1, U49.P3
SCL98: J98.4, R244.1, U49.P6
SCL99: J99.4, R247.1, U50.P3
SCL100: J100.4, R249.1, U50.P6
SDA1: J1.3, R1.1, U1.P4
SDA2: J2.3, R5.1, U1.P5
SDA3: J3.3, R6.1, U2.P4
SDA4: J4.3, R10.1, U2.P5
SDA5: J5.3, R11.1, U3.P4
SDA6: J6.3, R15.1, U3.P5
SDA7: J7.3, R16.1, U4.P4
SDA8: J8.3, R20.1, U4.P5
SDA9: J9.3, R21.1, U5.P4
SDA10: J10.3, R25.1, U5.P5
SDA11: J11.3, R26.1, U6.P4
SDA12: J12.3, R30.1, U6.P5
SDA13: J13.3, R31.1, U7.P4
SDA14: J14.3, R35.1, U7.P5
SDA15: J15.3, R36.1, U8.P4
SDA16: J16.3, R40.1, U8.P5
SDA17: J17.3, R41.1, U9.P4
SDA18: J18.3, R45.1, U9.P5
SDA19: J19.3, R46.1, U10.P4
SDA20: J20.3, R50.1, U10.P5
SDA21: J21.3, R51.1, U11.P4
SDA22: J22.3, R55.1, U11.P5
SDA23: J23.3, R56.1, U12.P4
SDA24: J24.3, R60.1, U12.P5
SDA25: J25.3, R61.1, U13.P4
SDA26: J26.3, R65.1, U13.P5
SDA27: J27.3, R66.1, U14.P4
SDA28: J28.3, R70.1, U14.P5
SDA29: J29.3, R71.1, U15.P4
SDA30: J30.3, R75.1, U15.P5
SDA31: J31.3, R76.1, U16.P4
SDA32: J32.3, R80.1, U16.P5
SDA33: J33.3, R81.1, U17.P4
SDA34: J34.3, R85.1, U17.P5
SDA35: J35.3, R86.1, U18.P4
SDA36: J36.3, R90.1, U18.P5
SDA37: J37.3, R91.1, U19.P4
SDA38: J38.3, R95.1, U19.P5
SDA39: J39.3, R96.1, U20.P4
SDA40: J40.3, R100.1, U20.P5
SDA41: J41.3, R101.1, U21.P4
SDA42: J42.3, R105.1, U21.P5
SDA43: J43.3, R106.1, U22.P4
SDA44: J44.3, R110.1, U22.P5
SDA45: J45.3, R111.1, U23.P4
SDA46: J46.3, R115.1, U23.P5
SDA47: J47.3, R116.1, U24.P4
SDA48: J48.3, R120.1, U24.P5
SDA49: J49.3, R121.1, U25.P4
SDA50: J50.3, R125.1, U25.P5
SDA51: J51.3, R126.1, U26.P4
SDA52: J52.3, R130.1, U26.P5
SDA53: J53.3, R131.1, U27.P4
SDA54: J54.3, R135.1, U27.P5
SDA55: J55.3, R136.1, U28.P4
SDA56: J56.3, R140.1, U28.P5
SDA57: J57.3, R141.1, U29.P4
SDA58: J58.3, R145.1, U29.P5
SDA59: J59.3, R146.1, U30.P4
SDA60: J60.3, R150.1, U30.P5
SDA61: J61.3, R151.1, U31.P4
SDA62: J62.3, R155.1, U31.P5
SDA63: J63.3, R156.1, U32.P4
SDA64: J64.3, R160.1, U32.P5
SDA65: J65.3, R161.1, U33.P4
SDA66: J66.3, R165.1, U33.P5
SDA67: J67.3, R166.1, U34.P4
SDA68: J68.3, R170.1, U34.P5
SDA69: J69.3, R171.1, U35.P4
SDA70: J70.3, R175.1, U35.P5
SDA71: J71.3, R176.1, U36.P4
SDA72: J72.3, R180.1, U36.P5
SDA73: J73.3, R181.1, U37.P4
SDA74: J74.3, R185.1, U37.P5
SDA75: J75.3, R186.1, U38.P4
SDA76: J76.3, R190.1, U38.P5
SDA77: J77.3, R191.1, U39.P4
SDA78: J78.3, R195.1, U39.P5
SDA79: J79.3, R196.1, U40.P4
SDA80: J80.3, R200.1, U40.P5
SDA81: J81.3, R201.1, U41.P4
SDA82: J82.3, R205.1, U41.P5
SDA83: J83.3, R206.1, U42.P4
SDA84: J84.3, R210.1, U42.P5
SDA85: J85.3, R211.1, U43.P4
SDA86: J86.3, R215.1, U43.P5
SDA87: J87.3, R216.1, U44.P4
SDA88: J88.3, R220.1, U44.P5
SDA89: J89.3, R221.1, U45.P4
SDA90: J90.3, R225.1, U45.P5
SDA91: J91.3, R226.1, U46.P4
SDA92: J92.3, R230.1, U46.P5
SDA93: J93.3, R231.1, U47.P4
SDA94: J94.3, R235.1, U47.P5
SDA95: J95.3, R236.1, U48.P4
SDA96: J96.3, R240.1, U48.P5
SDA97: J97.3, R241.1, U49.P4
SDA98: J98.3, R245.1, U49.P5
SDA99: J99.3, R246.1, U50.P4
SDA100: J100.3, R250.1, U50.P5
VREF1: J1.2, R1.2, R2.2, U1.P2
VREF2: J2.2, JP1.3, R4.2, R5.2
VREF2_IN: C1.1, R3.1, U1.P7, U1.P8
VREF2_IN1: C2.1, R8.1, U2.P7, U2.P8
VREF2_IN2: C3.1, R13.1, U3.P7, U3.P8
VREF2_IN3: C4.1, R18.1, U4.P7, U4.P8
VREF2_IN4: C5.1, R23.1, U5.P7, U5.P8
VREF2_IN5: C6.1, R28.1, U6.P7, U6.P8
VREF2_IN6: C7.1, R33.1, U7.P7, U7.P8
VREF2_IN7: C8.1, R38.1, U8.P7, U8.P8
VREF2_IN8: C9.1, R43.1, U9.P7, U9.P8
VREF2_IN9: C10.1, R48.1, U10.P7, U10.P8
VREF2_IN10: C11.1, R53.1, U11.P7, U11.P8
VREF2_IN11: C12.1, R58.1, U12.P7, U12.P8
VREF2_IN12: C13.1, R63.1, U13.P7, U13.P8
VREF2_IN13: C14.1, R68.1, U14.P7, U14.P8
VREF2_IN14: C15.1, R73.1, U15.P7, U15.P8
VREF2_IN15: C16.1, R78.1, U16.P7, U16.P8
VREF2_IN16: C17.1, R83.1, U17.P7, U17.P8
VREF2_IN17: C18.1, R88.1, U18.P7, U18.P8
VREF2_IN18: C19.1, R93.1, U19.P7, U19.P8
VREF2_IN19: C20.1, R98.1, U20.P7, U20.P8
VREF2_IN20: C21.1, R103.1, U21.P7, U21.P8
VREF2_IN21: C22.1, R108.1, U22.P7, U22.P8
VREF2_IN22: C23.1, R113.1, U23.P7, U23.P8
VREF2_IN23: C24.1, R118.1, U24.P7, U24.P8
VREF2_IN24: C25.1, R123.1, U25.P7, U25.P8
VREF2_IN25: C26.1, R128.1, U26.P7, U26.P8
VREF2_IN26: C27.1, R133.1, U27.P7, U27.P8
VREF2_IN27: C28.1, R138.1, U28.P7, U28.P8
VREF2_IN28: C29.1, R143.1, U29.P7, U29.P8
VREF2_IN29: C30.1, R148.1, U30.P7, U30.P8
VREF2_IN30: C31.1, R153.1, U31.P7, U31.P8
VREF2_IN31: C32.1, R158.1, U32.P7, U32.P8
VREF2_IN32: C33.1, R163.1, U33.P7, U33.P8
VREF2_IN33: C34.1, R168.1, U34.P7, U34.P8
VREF2_IN34: C35.1, R173.1, U35.P7, U35.P8
VREF2_IN35: C36.1, R178.1, U36.P7, U36.P8
VREF2_IN36: C37.1, R183.1, U37.P7, U37.P8
VREF2_IN37: C38.1, R188.1, U38.P7, U38.P8
VREF2_IN38: C39.1, R193.1, U39.P7, U39.P8
VREF2_IN39: C40.1, R198.1, U40.P7, U40.P8
VREF2_IN40: C41.1, R203.1, U41.P7, U41.P8
VREF2_IN41: C42.1, R208.1, U42.P7, U42.P8
VREF2_IN42: C43.1, R213.1, U43.P7, U43.P8
VREF2_IN43: C44.1, R218.1, U44.P7, U44.P8
VREF2_IN44: C45.1, R223.1, U45.P7, U45.P8
VREF2_IN45: C46.1, R228.1, U46.P7, U46.P8
VREF2_IN46: C47.1, R233.1, U47.P7, U47.P8
VREF2_IN47: C48.1, R238.1, U48.P7, U48.P8
VREF2_IN48: C49.1, R243.1, U49.P7, U49.P8
VREF2_IN49: C50.1, R248.1, U50.P7, U50.P8
VREF3: J4.2, JP2.3, R9.2, R10.2
VREF4: J3.2, R6.2, R7.2, U2.P2
VREF5: J6.2, JP3.3, R14.2, R15.2
VREF6: J5.2, R11.2, R12.2, U3.P2
VREF7: J8.2, JP4.3, R19.2, R20.2
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

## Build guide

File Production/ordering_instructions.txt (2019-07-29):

panel size, 111x146mm
PCB thickness, 1.6mm
number of layers, 2
soldermask color, Red
silkscreen color, White
oz copper, 1oz
finish, HASL lead free
stencils, bottom
pcs per panel, 50
min trace width, 0.254000mm / 0.010000in
min drill size, 0.381000mm / 0.015000in

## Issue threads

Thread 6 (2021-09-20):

qwiic level translator?

egregori3, 2021-09-20:
It would be great to have a board like this with qwiic headers on both sides.
I need to connect a 1.8v I2C master to some qwiic sensors and the qwiic cables are so convenient.

nseidle, 2021-09-21:
A fine idea. Going on the to do list!

nseidle, 2022-03-10:
The Qwiic 1.8V adapter is available [here](https://www.sparkfun.com/products/19017) if you need it. Thanks for the recommendation!

Closed 2022-03-10.

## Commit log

2013-06-04 Updated README and revised board files to v14
    [PCA9306_Breakout.brd, PCA9306_Breakout.sch]
2013-06-11 Rerouted traces away from IC and changed packages to 0603. Add labels to the schematic on the header pins.
    [PCA9306_Breakout.brd, PCA9306_Breakout.sch]
2013-07-03 Updating layout
    [PCA9306_Breakout.brd]
2013-07-03 Fixed font size on schematic labels.
    [PCA9306_Breakout.sch]
2013-07-08 Production ready v14
    created panel
    [PCA9306_Breakout Panel v14.brd]
2013-08-29 Checking 1:1 FP on IC
    [PCA9306_Breakout.brd, PCA9306_Breakout.sch]
2013-10-02 Panel Created
    [PCA9306_Breakout Panel v14.brd, PCA9306_Breakout-Panel-v14.brd]
2019-06-04 Documentation added for v20
    [PCA9306_Breakout.brd, PCA9306_Breakout.sch]
2019-06-11 Adds slik lables, adds jumper for enable pin, increases size by 10 mils in both x and y direction, updates PCA9306 to new package
    [PCA9306_Breakout.brd, PCA9306_Breakout.sch]
2019-06-12 Adds an additional PTH header for GND on VREF2 side
    [PCA9306_Breakout.brd, PCA9306_Breakout.sch]
2019-06-13 Moves Open Hardware symbol
    [PCA9306_Breakout.brd]
2019-06-13 Moves passives to lower half of board, resulting in full retrace of board....
    *Adds HIGH/LOW silk to board
    *Adds triple jumper to correctly add enable feature
    *Changes 0.1uF capacitor to 100pF capacitor
    [PCA9306_Breakout.brd, PCA9306_Breakout.sch]
2019-06-14 Updates silk on jumper and "HIGH" and "LOW" voltages on bottom, renumbers parts in schematic
    [PCA9306_Breakout.brd, PCA9306_Breakout.sch]
2019-06-17 Fixes traces for both data lines, corrects punctuation of schematic note.
    [PCA9306_Breakout.brd, PCA9306_Breakout.sch]
2019-06-17 Updates SKU for new level translator
    [PCA9306_Breakout.brd, PCA9306_Breakout.sch]
2019-06-17 Changes version number to v20
    [PCA9306_Breakout.brd, PCA9306_Breakout.sch]
2019-06-17 Changes name of board files ONLY
    [SparkFun_Level_Translator_PCA9306.brd, SparkFun_Level_Translator_PCA9306.sch]
2019-06-17 Changes label to "Switch" rather than shorthand "Swch"
    [PCA9306_Breakout-Panel-v14.brd]
2019-06-17 Adds production files
    [SparkFun_Level_Translator_PCA9306-Panel.brd, SparkFun_Level_Translator_PCA9306.brd]
2019-07-18 Updates enable text in schematic
    [SparkFun_Level_Translator_PCA9306.sch]

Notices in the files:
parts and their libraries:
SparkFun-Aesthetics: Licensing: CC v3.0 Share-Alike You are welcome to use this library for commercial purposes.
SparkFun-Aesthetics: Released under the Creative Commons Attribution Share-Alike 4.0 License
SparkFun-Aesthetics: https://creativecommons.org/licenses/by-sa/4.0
